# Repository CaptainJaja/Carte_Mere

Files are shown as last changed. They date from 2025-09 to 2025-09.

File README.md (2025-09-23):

# Carte mère – Coupe de France de Robotique

> Carte mère basée sur un **STM32H5** en boîtier **LQFP177**.  
> Conçue pour centraliser la communication et le pilotage des modules du robot, avec une connectique optimisée pour la robustesse et la modularité.

---

## Caractéristiques principales

- **Microcontrôleur** : STM32H5, LQFP177  
- **Interfaces série** : 12 UARTs, chacun exposé sur connecteurs **VCC – GND – TX – GND – RX** afin de permettre le torsadage avec un retour GND pour une meilleure intégrité du signal  
- **Bus I²C** : 3 bus indépendants, jusqu’à **13 connexions** possibles (chaque connecteur fournit 2 GPIOs, GND et 3V3)  
- **Convertisseurs analogiques (ADC)** : 12 entrées, rangées avec alimentation 3V3 et GND pour faciliter le câblage  
- **USB-C** : un connecteur intégré pour programmation et alimentation  
- **Timers** : 12 broches disponibles pour PWM et capture/compare  
- **GPIO** : 10 broches générales, chacune associée à GND et 3V3 pour plus de flexibilité  
- **SPI** : 4 full duplex master, avec chacun des broches power et deux gpios 

---

## Vues du PCB

### Face composants
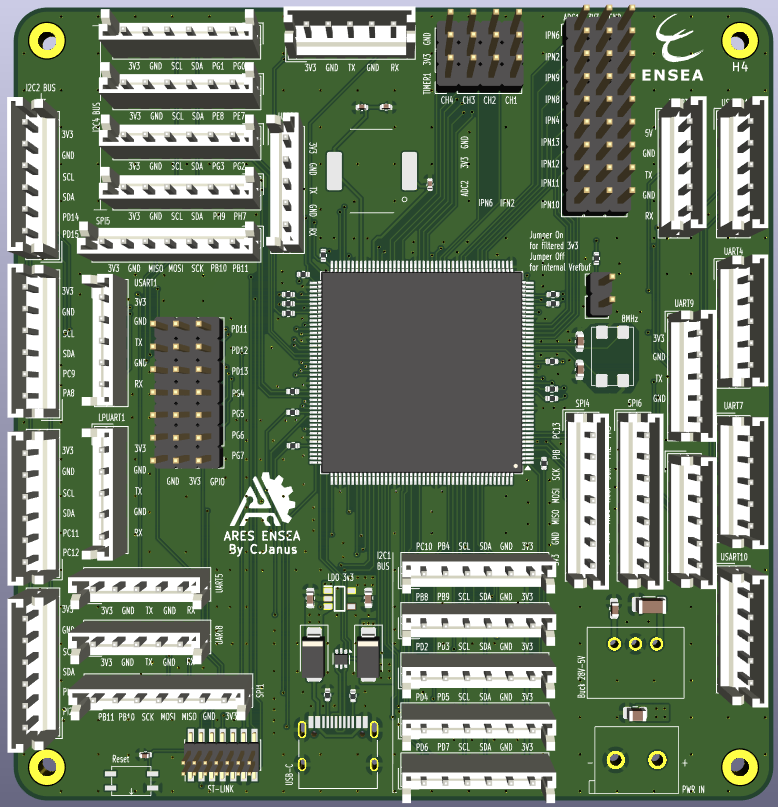
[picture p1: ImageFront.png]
PCB Face


### Face cuivre arrière
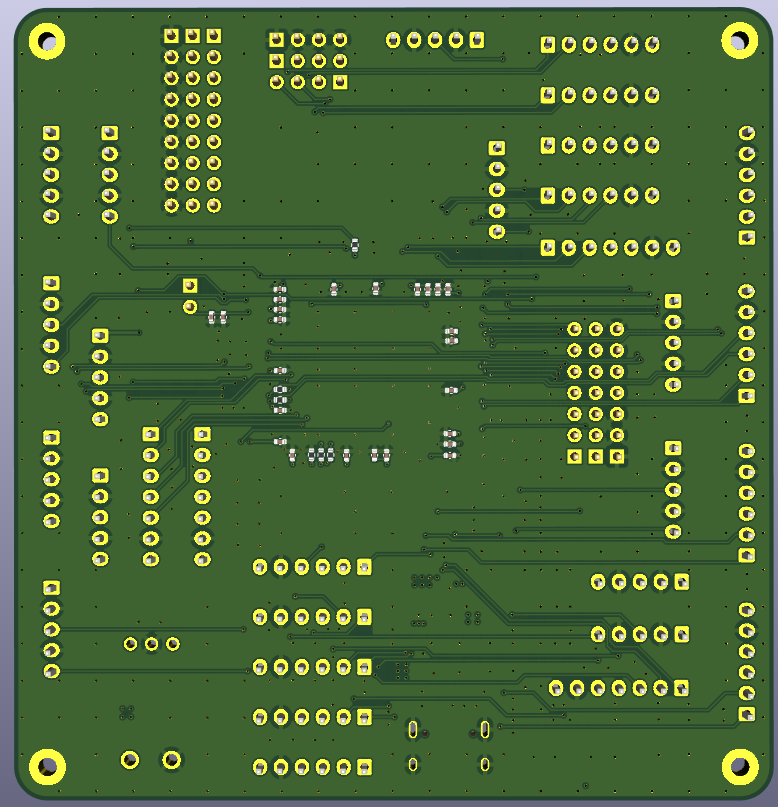
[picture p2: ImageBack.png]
PCB Dos


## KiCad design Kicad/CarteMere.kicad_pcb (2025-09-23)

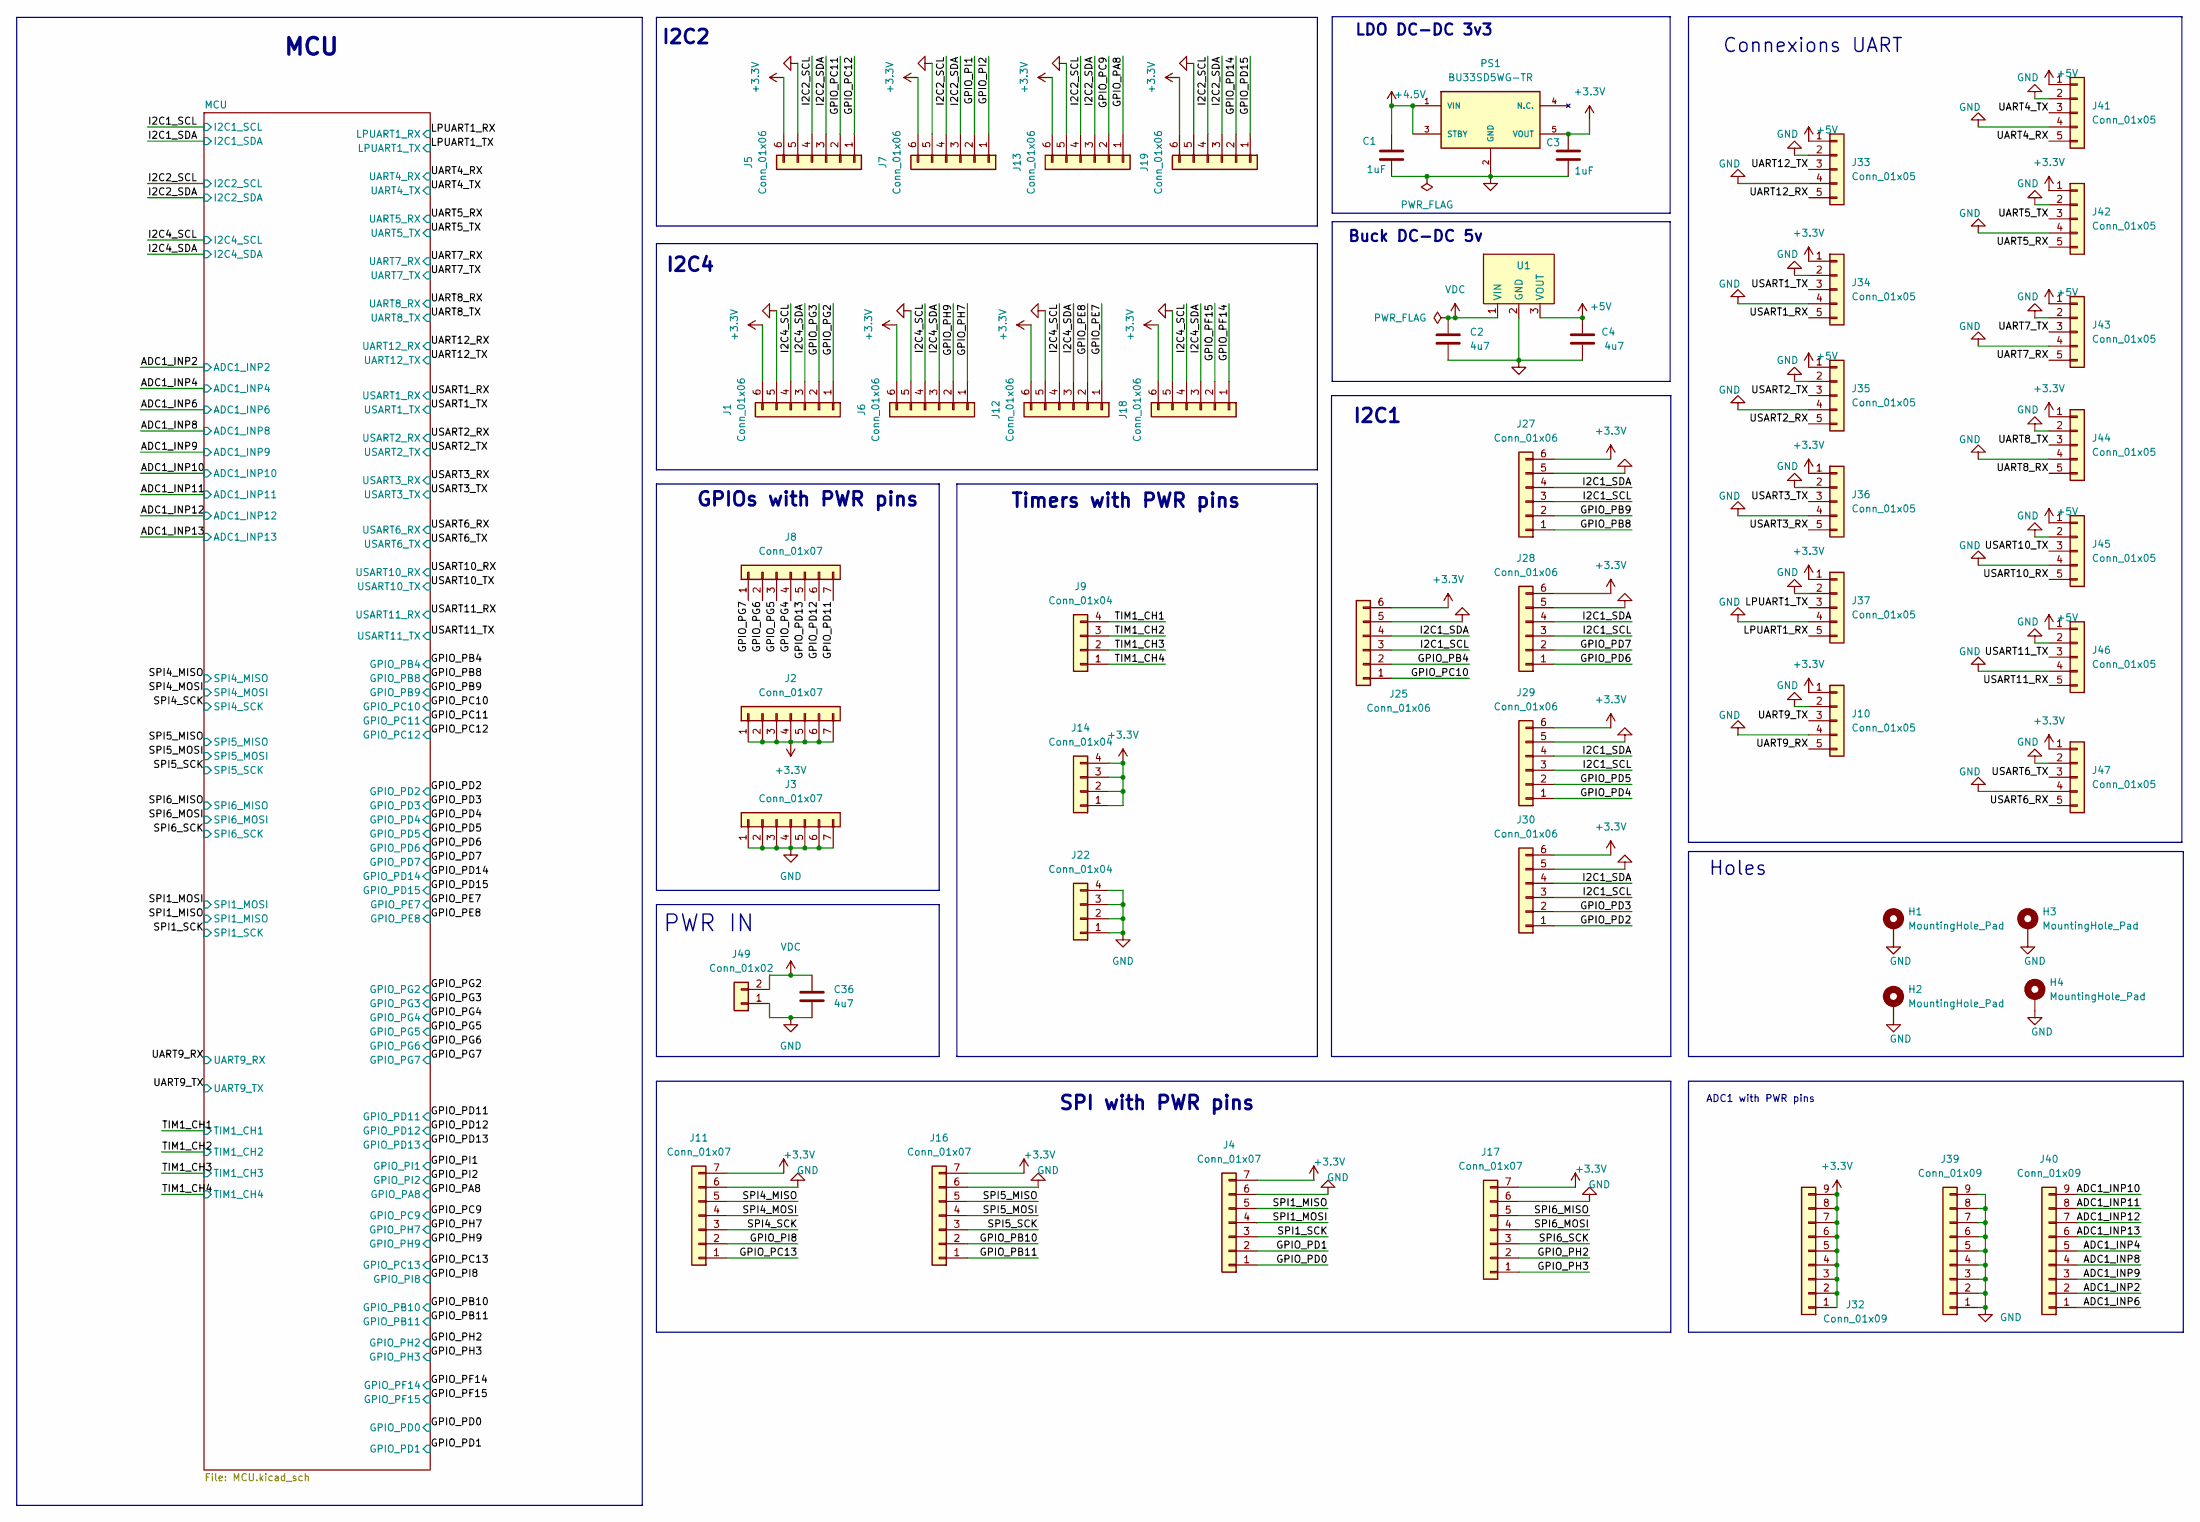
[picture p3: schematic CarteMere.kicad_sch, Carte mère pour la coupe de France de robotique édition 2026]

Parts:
C1, C3: 1uF; C_0603_1608Metric
C2: 4u7; C_1206_3216Metric
C4: 4u7; C_0603_1608Metric
C36: 4u7; C_0805_2012Metric
H1, H2, H3, H4: MountingHole_Pad; MountingHole_2.2mm_M2_Pad
J1, J5, J6, J7, J12, J13, J18, J19, J25, J27, J28, J29, J30: Conn_01x06; JST_EH_B6B-EH-A_1x06_P2.50mm_Vertical
J2, J3, J8: Conn_01x07; PinHeader_1x07_P2.54mm_Vertical
J4, J11, J16, J17: Conn_01x07; JST_EH_B7B-EH-A_1x07_P2.50mm_Vertical
J9, J14, J22: Conn_01x04; PinHeader_1x04_P2.54mm_Vertical
J10, J33, J34, J35, J36, J37, J41, J42, J43, J44, J45, J46, J47: Conn_01x05; JST_EH_B5B-EH-A_1x05_P2.50mm_Vertical
J32, J39, J40: Conn_01x09; PinHeader_1x09_P2.54mm_Vertical
J49: Conn_01x02; KF301-5.0-2P
PS1: BU33SD5WG-TR; SOT95P280X125-5N; Mouser_Part_Number 755-BU33SD5WG-TR
U1: StepDown3v3; MPN 173010x78

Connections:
+3.3V: C3.1, J1.6, J2.1, J2.2, J2.3, J2.4, J2.5, J2.6, J2.7, J4.7, J5.6, J6.6, J7.6, J10.1, J11.7, J12.6, J13.6, J14.1, J14.2, J14.3, J14.4, J16.7, J17.7, J18.6, J19.6, J25.6, J27.6, J28.6, J29.6, J30.6, J32.1, J32.2, J32.3, J32.4, J32.5, J32.6, J32.7, J32.8, J32.9, J34.1, J36.1, J37.1, J42.1, J44.1, J47.1, PS1.5 (VOUT); also elsewhere on the board
+4.5V: C1.1, PS1.1 (VIN), PS1.3 (STBY); also elsewhere on the board
+5V: C4.1, J33.1, J35.1, J41.1, J43.1, J45.1, J46.1, U1.3 (VOUT); also elsewhere on the board
/ADC1_INP2: J40.2; also elsewhere on the board
/ADC1_INP4: J40.5; also elsewhere on the board
/ADC1_INP6: J40.1; also elsewhere on the board
/ADC1_INP8: J40.4; also elsewhere on the board
/ADC1_INP9: J40.3; also elsewhere on the board
/ADC1_INP10: J40.9; also elsewhere on the board
/ADC1_INP11: J40.8; also elsewhere on the board
/ADC1_INP12: J40.7; also elsewhere on the board
/ADC1_INP13: J40.6; also elsewhere on the board
/GPIO_PA8: J13.1; also elsewhere on the board
/GPIO_PB4: J25.2; also elsewhere on the board
/GPIO_PB8: J27.1; also elsewhere on the board
/GPIO_PB9: J27.2; also elsewhere on the board
/GPIO_PB10: J16.2; also elsewhere on the board
/GPIO_PB11: J16.1; also elsewhere on the board
/GPIO_PC9: J13.2; also elsewhere on the board
/GPIO_PC10: J25.1; also elsewhere on the board
/GPIO_PC11: J5.2; also elsewhere on the board
/GPIO_PC12: J5.1; also elsewhere on the board
/GPIO_PC13: J11.1; also elsewhere on the board
/GPIO_PD0: J4.1; also elsewhere on the board
/GPIO_PD1: J4.2; also elsewhere on the board
/GPIO_PD2: J30.1; also elsewhere on the board
/GPIO_PD3: J30.2; also elsewhere on the board
/GPIO_PD4: J29.1; also elsewhere on the board
/GPIO_PD5: J29.2; also elsewhere on the board
/GPIO_PD6: J28.1; also elsewhere on the board
/GPIO_PD7: J28.2; also elsewhere on the board
/GPIO_PD11: J8.7; also elsewhere on the board
/GPIO_PD12: J8.6; also elsewhere on the board
/GPIO_PD13: J8.5; also elsewhere on the board
/GPIO_PD14: J19.2; also elsewhere on the board
/GPIO_PD15: J19.1; also elsewhere on the board
/GPIO_PE7: J12.1; also elsewhere on the board
/GPIO_PE8: J12.2; also elsewhere on the board
/GPIO_PF14: J18.1; also elsewhere on the board
/GPIO_PF15: J18.2; also elsewhere on the board
/GPIO_PG2: J1.1; also elsewhere on the board
/GPIO_PG3: J1.2; also elsewhere on the board
/GPIO_PG4: J8.4; also elsewhere on the board
/GPIO_PG5: J8.3; also elsewhere on the board
/GPIO_PG6: J8.2; also elsewhere on the board
/GPIO_PG7: J8.1; also elsewhere on the board
/GPIO_PH2: J17.2; also elsewhere on the board
/GPIO_PH3: J17.1; also elsewhere on the board
/GPIO_PH7: J6.1; also elsewhere on the board
/GPIO_PH9: J6.2; also elsewhere on the board
/GPIO_PI1: J7.2; also elsewhere on the board
/GPIO_PI2: J7.1; also elsewhere on the board
/GPIO_PI8: J11.2; also elsewhere on the board
/I2C1_SCL: J25.3, J27.3, J28.3, J29.3, J30.3; also elsewhere on the board
/I2C1_SDA: J25.4, J27.4, J28.4, J29.4, J30.4; also elsewhere on the board
/I2C2_SCL: J5.4, J7.4, J13.4, J19.4; also elsewhere on the board
/I2C2_SDA: J5.3, J7.3, J13.3, J19.3; also elsewhere on the board
/I2C4_SCL: J1.4, J6.4, J12.4, J18.4; also elsewhere on the board
/I2C4_SDA: J1.3, J6.3, J12.3, J18.3; also elsewhere on the board
/LPUART1_RX: J37.5; also elsewhere on the board
/LPUART1_TX: J37.3; also elsewhere on the board
/SPI1_MISO: J4.5; also elsewhere on the board
/SPI1_MOSI: J4.4; also elsewhere on the board
/SPI1_SCK: J4.3; also elsewhere on the board
/SPI4_MISO: J11.5; also elsewhere on the board
/SPI4_MOSI: J11.4; also elsewhere on the board
/SPI4_SCK: J11.3; also elsewhere on the board
/SPI5_MISO: J16.5; also elsewhere on the board
/SPI5_MOSI: J16.4; also elsewhere on the board
/SPI5_SCK: J16.3; also elsewhere on the board
/SPI6_MISO: J17.5; also elsewhere on the board
/SPI6_MOSI: J17.4; also elsewhere on the board
/SPI6_SCK: J17.3; also elsewhere on the board
/TIM1_CH1: J9.4; also elsewhere on the board
/TIM1_CH2: J9.3; also elsewhere on the board
/TIM1_CH3: J9.2; also elsewhere on the board
/TIM1_CH4: J9.1; also elsewhere on the board
/UART4_RX: J41.5; also elsewhere on the board
/UART4_TX: J41.3; also elsewhere on the board
/UART5_RX: J42.5; also elsewhere on the board
/UART5_TX: J42.3; also elsewhere on the board
/UART7_RX: J43.5; also elsewhere on the board
/UART7_TX: J43.3; also elsewhere on the board
/UART8_RX: J44.5; also elsewhere on the board
/UART8_TX: J44.3; also elsewhere on the board
/UART9_RX: J10.5; also elsewhere on the board
/UART9_TX: J10.3; also elsewhere on the board
/UART12_RX: J33.5; also elsewhere on the board
/UART12_TX: J33.3; also elsewhere on the board
/USART1_RX: J34.5; also elsewhere on the board
/USART1_TX: J34.3; also elsewhere on the board
/USART2_RX: J35.5; also elsewhere on the board
/USART2_TX: J35.3; also elsewhere on the board
/USART3_RX: J36.5; also elsewhere on the board
/USART3_TX: J36.3; also elsewhere on the board
/USART6_RX: J47.5; also elsewhere on the board
/USART6_TX: J47.3; also elsewhere on the board
/USART10_RX: J45.5; also elsewhere on the board
/USART10_TX: J45.3; also elsewhere on the board
/USART11_RX: J46.5; also elsewhere on the board
/USART11_TX: J46.3; also elsewhere on the board
GND: C1.2, C2.2, C3.2, C4.2, C36.2, H1.1, H2.1, H3.1, H4.1, J1.5, J3.1, J3.2, J3.3, J3.4, J3.5, J3.6, J3.7, J4.6, J5.5, J6.5, J7.5, J10.2, J10.4, J11.6, J12.5, J13.5, J16.6, J17.6, J18.5, J19.5, J22.1, J22.2, J22.3, J22.4, J25.5, J27.5, J28.5, J29.5, J30.5, J33.2, J33.4, J34.2, J34.4, J35.2, J35.4, J36.2, J36.4, J37.2, J37.4, J39.1, J39.2, J39.3, J39.4, J39.5, J39.6, J39.7, J39.8, J39.9, J41.2, J41.4, J42.2, J42.4, J43.2, J43.4, J44.2, J44.4, J45.2, J45.4, J46.2, J46.4, J47.2, J47.4, J49.1, PS1.2 (GND), U1.2 (GND); also elsewhere on the board
VDC: C2.1, C36.1, J49.2, U1.1 (VIN)

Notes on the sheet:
SPI with PWR pins
I2C2
MCU
PWR IN
I2C4
Connexions UART
Buck DC-DC 5v
LDO DC-DC 3v3
GPIOs with PWR pins
Timers with PWR pins
I2C1
ADC1 with PWR pins
Holes

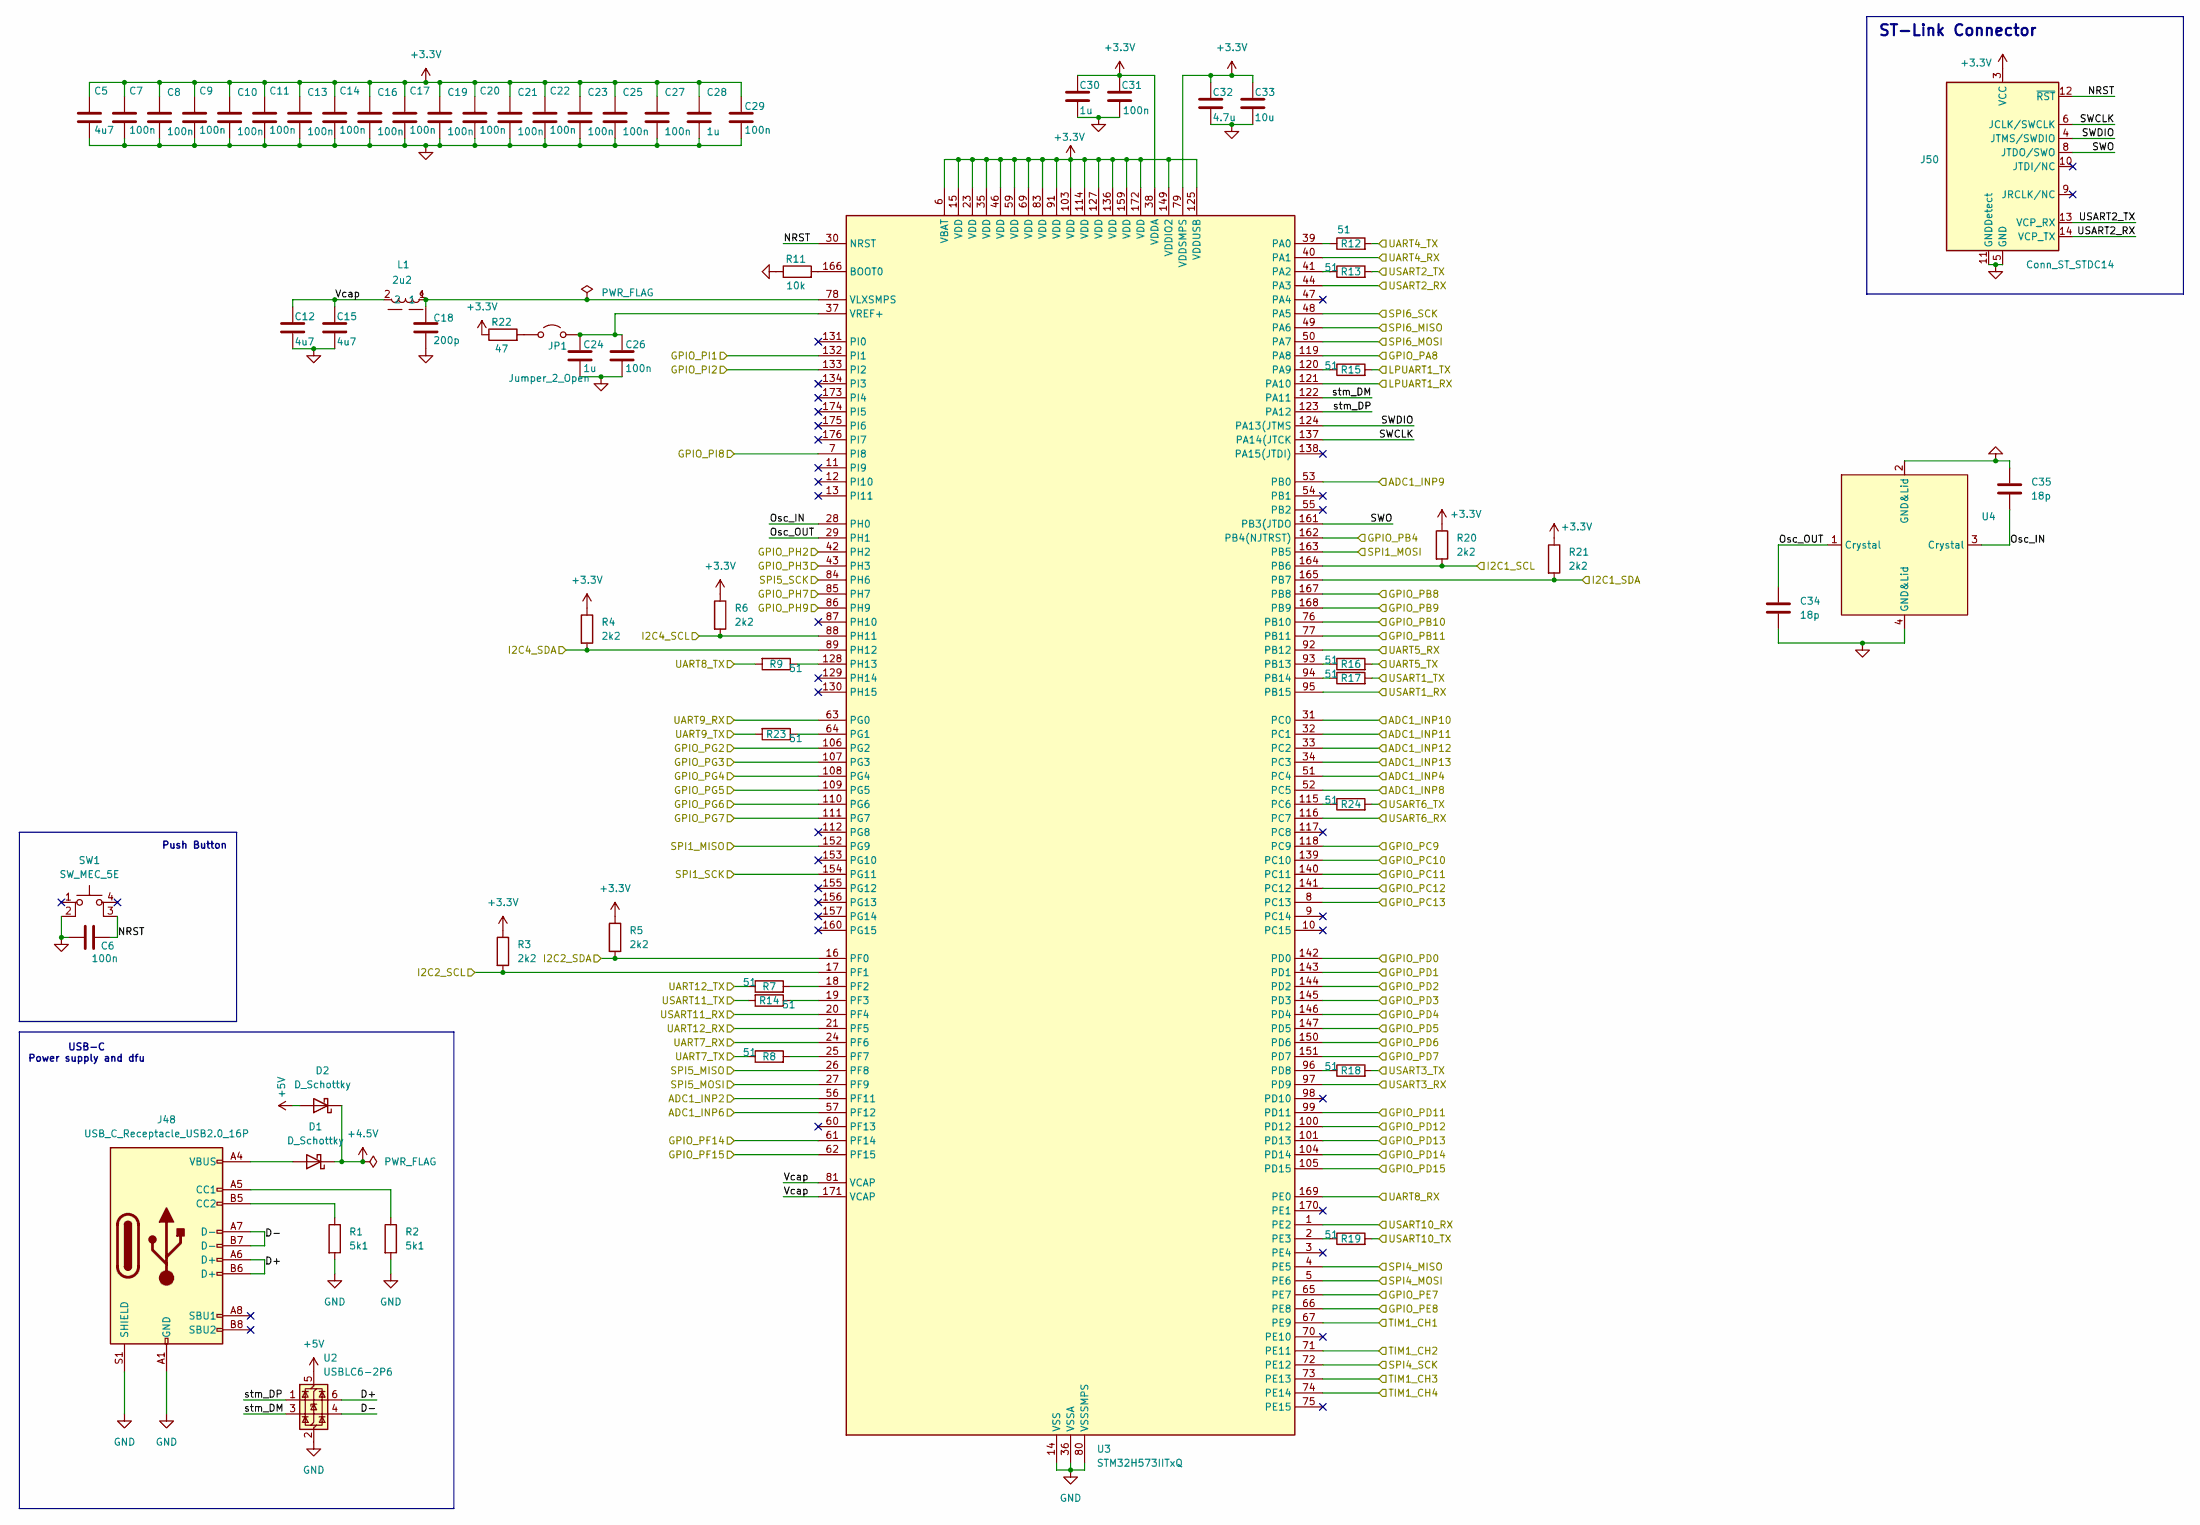
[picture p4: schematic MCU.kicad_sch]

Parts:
C5, C12, C15: 4u7; C_0402_1005Metric
C6, C7, C8, C9, C10, C11, C13, C14, C16, C17, C19, C20, C21, C22, C23, C25, C26, C27, C29, C31: 100n; C_0402_1005Metric
C18: 200p; C_0402_1005Metric
C24, C28, C30: 1u; C_0402_1005Metric
C32: 4.7u; C_0402_1005Metric
C33: 10u; C_0402_1005Metric
C34, C35: 18p; C_0603_1608Metric
D1, D2: D_Schottky; D_SMA
J48: USB_C_Receptacle_USB2.0_16P; USB_C_Receptacle_HRO_TYPE-C-31-M-12
J50: Conn_ST_STDC14; PinHeader_2x07_P1.27mm_Vertical_SMD
JP1: Jumper_2_Open; PinHeader_1x02_P2.54mm_Vertical
L1: 2u2; 7440660022
R1, R2: 5k1; R_0402_1005Metric
R3, R4, R5, R6, R20, R21: 2k2; R_0402_1005Metric
R7, R8, R9, R12, R13, R14, R15, R16, R17, R18, R19, R23, R24: 51; R_0402_1005Metric
R11: 10k; R_0402_1005Metric
R22: 47; R_0402_1005Metric
SW1: SW_MEC_5E; WS-TASU SMT Tact Switch 4.7x3.5 mm side push
U2: USBLC6-2P6; SOT-666
U3: STM32H573IITxQ; LQFP-176_24x24mm_P0.5mm
U4: WE-XTAL Quartz Crystal 8MHz

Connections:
+3.3V: C5.1, C7.1, C8.1, C9.1, C10.1, C11.1, C13.1, C14.1, C16.1, C17.1, C19.1, C20.1, C21.1, C22.1, C23.1, C25.1, C27.1, C28.1, C29.1, C30.1, C31.1, C32.1, C33.1, J50.3 (VCC), R3.1, R4.1, R5.1, R6.1, R20.1, R21.1, R22.1, U3.6 (VBAT), U3.15 (VDD), U3.23 (VDD), U3.35 (VDD), U3.38 (VDDA), U3.46 (VDD), U3.59 (VDD), U3.69 (VDD), U3.79 (VDDSMPS), U3.83 (VDD), U3.91 (VDD), U3.103 (VDD), U3.114 (VDD), U3.125 (VDDUSB), U3.127 (VDD), U3.136 (VDD), U3.149 (VDDIO2), U3.159 (VDD), U3.172 (VDD); also elsewhere on the board
+4.5V: D1.1 (K), D2.1 (K); also elsewhere on the board
+5V: D2.2 (A), U2.5 (VBUS); also elsewhere on the board
/ADC1_INP2: U3.56 (PF11); also elsewhere on the board
/ADC1_INP4: U3.51 (PC4); also elsewhere on the board
/ADC1_INP6: U3.57 (PF12); also elsewhere on the board
/ADC1_INP8: U3.52 (PC5); also elsewhere on the board
/ADC1_INP9: U3.53 (PB0); also elsewhere on the board
/ADC1_INP10: U3.31 (PC0); also elsewhere on the board
/ADC1_INP11: U3.32 (PC1); also elsewhere on the board
/ADC1_INP12: U3.33 (PC2); also elsewhere on the board
/ADC1_INP13: U3.34 (PC3); also elsewhere on the board
/GPIO_PA8: U3.119 (PA8); also elsewhere on the board
/GPIO_PB4: U3.162 (PB4(NJTRST)); also elsewhere on the board
/GPIO_PB8: U3.167 (PB8); also elsewhere on the board
/GPIO_PB9: U3.168 (PB9); also elsewhere on the board
/GPIO_PB10: U3.76 (PB10); also elsewhere on the board
/GPIO_PB11: U3.77 (PB11); also elsewhere on the board
/GPIO_PC9: U3.118 (PC9); also elsewhere on the board
/GPIO_PC10: U3.139 (PC10); also elsewhere on the board
/GPIO_PC11: U3.140 (PC11); also elsewhere on the board
/GPIO_PC12: U3.141 (PC12); also elsewhere on the board
/GPIO_PC13: U3.8 (PC13); also elsewhere on the board
/GPIO_PD0: U3.142 (PD0); also elsewhere on the board
/GPIO_PD1: U3.143 (PD1); also elsewhere on the board
/GPIO_PD2: U3.144 (PD2); also elsewhere on the board
/GPIO_PD3: U3.145 (PD3); also elsewhere on the board
/GPIO_PD4: U3.146 (PD4); also elsewhere on the board
/GPIO_PD5: U3.147 (PD5); also elsewhere on the board
/GPIO_PD6: U3.150 (PD6); also elsewhere on the board
/GPIO_PD7: U3.151 (PD7); also elsewhere on the board
/GPIO_PD11: U3.99 (PD11); also elsewhere on the board
/GPIO_PD12: U3.100 (PD12); also elsewhere on the board
/GPIO_PD13: U3.101 (PD13); also elsewhere on the board
/GPIO_PD14: U3.104 (PD14); also elsewhere on the board
/GPIO_PD15: U3.105 (PD15); also elsewhere on the board
/GPIO_PE7: U3.65 (PE7); also elsewhere on the board
/GPIO_PE8: U3.66 (PE8); also elsewhere on the board
/GPIO_PF14: U3.61 (PF14); also elsewhere on the board
/GPIO_PF15: U3.62 (PF15); also elsewhere on the board
/GPIO_PG2: U3.106 (PG2); also elsewhere on the board
/GPIO_PG3: U3.107 (PG3); also elsewhere on the board
/GPIO_PG4: U3.108 (PG4); also elsewhere on the board
/GPIO_PG5: U3.109 (PG5); also elsewhere on the board
/GPIO_PG6: U3.110 (PG6); also elsewhere on the board
/GPIO_PG7: U3.111 (PG7); also elsewhere on the board
/GPIO_PH2: U3.42 (PH2); also elsewhere on the board
/GPIO_PH3: U3.43 (PH3); also elsewhere on the board
/GPIO_PH7: U3.85 (PH7); also elsewhere on the board
/GPIO_PH9: U3.86 (PH9); also elsewhere on the board
/GPIO_PI1: U3.132 (PI1); also elsewhere on the board
/GPIO_PI2: U3.133 (PI2); also elsewhere on the board
/GPIO_PI8: U3.7 (PI8); also elsewhere on the board
/I2C1_SCL: R20.2, U3.164 (PB6); also elsewhere on the board
/I2C1_SDA: R21.2, U3.165 (PB7); also elsewhere on the board
/I2C2_SCL: R3.2, U3.17 (PF1); also elsewhere on the board
/I2C2_SDA: R5.2, U3.16 (PF0); also elsewhere on the board
/I2C4_SCL: R6.2, U3.88 (PH11); also elsewhere on the board
/I2C4_SDA: R4.2, U3.89 (PH12); also elsewhere on the board
/LPUART1_RX: U3.121 (PA10); also elsewhere on the board
/LPUART1_TX: R15.2; also elsewhere on the board
/MCU/D+: J48.A6 (D+), J48.B6 (D+), U2.6 (I/O1)
/MCU/D-: J48.A7 (D-), J48.B7 (D-), U2.4 (I/O2)
/MCU/NRST: C6.2, J50.12 (~RST), SW1.3 (K), U3.30 (NRST)
/MCU/Osc_IN: C35.2, U3.28 (PH0), U4.3 (Crystal)
/MCU/Osc_OUT: C34.1, U3.29 (PH1), U4.1 (Crystal)
/MCU/SWCLK: J50.6 (JCLK/SWCLK), U3.137 (PA14(JTCK)
/MCU/SWDIO: J50.4 (JTMS/SWDIO), U3.124 (PA13(JTMS)
/MCU/SWO: J50.8 (JTDO/SWO), U3.161 (PB3(JTDO)
/MCU/Vcap: C12.1, C15.1, L1.2, U3.81 (VCAP), U3.171 (VCAP)
/MCU/stm_DM: U2.3 (I/O2), U3.122 (PA11)
/MCU/stm_DP: U2.1 (I/O1), U3.123 (PA12)
/SPI1_MISO: U3.152 (PG9); also elsewhere on the board
/SPI1_MOSI: U3.163 (PB5); also elsewhere on the board
/SPI1_SCK: U3.154 (PG11); also elsewhere on the board
/SPI4_MISO: U3.4 (PE5); also elsewhere on the board
/SPI4_MOSI: U3.5 (PE6); also elsewhere on the board
/SPI4_SCK: U3.72 (PE12); also elsewhere on the board
/SPI5_MISO: U3.26 (PF8); also elsewhere on the board
/SPI5_MOSI: U3.27 (PF9); also elsewhere on the board
/SPI5_SCK: U3.84 (PH6); also elsewhere on the board
/SPI6_MISO: U3.49 (PA6); also elsewhere on the board
/SPI6_MOSI: U3.50 (PA7); also elsewhere on the board
/SPI6_SCK: U3.48 (PA5); also elsewhere on the board
/TIM1_CH1: U3.67 (PE9); also elsewhere on the board
/TIM1_CH2: U3.71 (PE11); also elsewhere on the board
/TIM1_CH3: U3.73 (PE13); also elsewhere on the board
/TIM1_CH4: U3.74 (PE14); also elsewhere on the board
/UART4_RX: U3.40 (PA1); also elsewhere on the board
/UART4_TX: R12.2; also elsewhere on the board
/UART5_RX: U3.92 (PB12); also elsewhere on the board
/UART5_TX: R16.2; also elsewhere on the board
/UART7_RX: U3.24 (PF6); also elsewhere on the board
/UART7_TX: R8.1; also elsewhere on the board
/UART8_RX: U3.169 (PE0); also elsewhere on the board
/UART8_TX: R9.2; also elsewhere on the board
/UART9_RX: U3.63 (PG0); also elsewhere on the board
/UART9_TX: R23.2; also elsewhere on the board
/UART12_RX: U3.21 (PF5); also elsewhere on the board
/UART12_TX: R7.1; also elsewhere on the board
/USART1_RX: U3.95 (PB15); also elsewhere on the board
/USART1_TX: R17.2; also elsewhere on the board
/USART2_RX: J50.14 (VCP_TX), U3.44 (PA3); also elsewhere on the board
/USART2_TX: J50.13 (VCP_RX), R13.2; also elsewhere on the board
/USART3_RX: U3.97 (PD9); also elsewhere on the board
/USART3_TX: R18.2; also elsewhere on the board
/USART6_RX: U3.116 (PC7); also elsewhere on the board
/USART6_TX: R24.2; also elsewhere on the board
/USART10_RX: U3.1 (PE2); also elsewhere on the board
/USART10_TX: R19.2; also elsewhere on the board
/USART11_RX: U3.20 (PF4); also elsewhere on the board
/USART11_TX: R14.2; also elsewhere on the board
GND: C5.2, C6.1, C7.2, C8.2, C9.2, C10.2, C11.2, C12.2, C13.2, C14.2, C15.2, C16.2, C17.2, C18.2, C19.2, C20.2, C21.2, C22.2, C23.2, C24.2, C25.2, C26.2, C27.2, C28.2, C29.2, C30.2, C31.2, C32.2, C33.2, C34.2, C35.1, J48.A1 (GND), J48.A12 (GND), J48.B1 (GND), J48.B12 (GND), J48.S1 (SHIELD), J50.5 (GND), J50.7 (GND), J50.11 (GNDDetect), R1.2, R2.2, R11.1, SW1.2, U2.2 (GND), U3.14 (VSS), U3.22 (VSS), U3.36 (VSSA), U3.45 (VSS), U3.58 (VSS), U3.68 (VSS), U3.80 (VSSSMPS), U3.82 (VSS), U3.90 (VSS), U3.102 (VSS), U3.113 (VSS), U3.126 (VSS), U3.135 (VSS), U3.148 (VSS), U3.158 (VSS), U4.2 (GND&Lid), U4.4 (GND&Lid); also elsewhere on the board
unnamed: D1.2 (A), J48.A4 (VBUS), J48.A9 (VBUS), J48.B4 (VBUS), J48.B9 (VBUS)
unnamed: J48.A5 (CC1), R2.1
unnamed: J48.B5 (CC2), R1.1
unnamed: JP1.1 (A), R22.2
unnamed: C24.1, C26.1, JP1.2 (B), U3.37 (VREF+)
unnamed: R11.2, U3.166 (BOOT0)
unnamed: R12.1, U3.39 (PA0)
unnamed: R13.1, U3.41 (PA2)
unnamed: R15.1, U3.120 (PA9)
unnamed: R16.1, U3.93 (PB13)
unnamed: R17.1, U3.94 (PB14)
unnamed: R24.1, U3.115 (PC6)
unnamed: R18.1, U3.96 (PD8)
unnamed: R19.1, U3.2 (PE3)
unnamed: R7.2, U3.18 (PF2)
unnamed: R14.1, U3.19 (PF3)
unnamed: R8.2, U3.25 (PF7)
unnamed: R23.1, U3.64 (PG1)
unnamed: R9.1, U3.128 (PH13)
unnamed: C18.1, L1.1, U3.78 (VLXSMPS)

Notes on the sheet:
USB-C Power supply and dfu
Push Button
ST-Link Connector

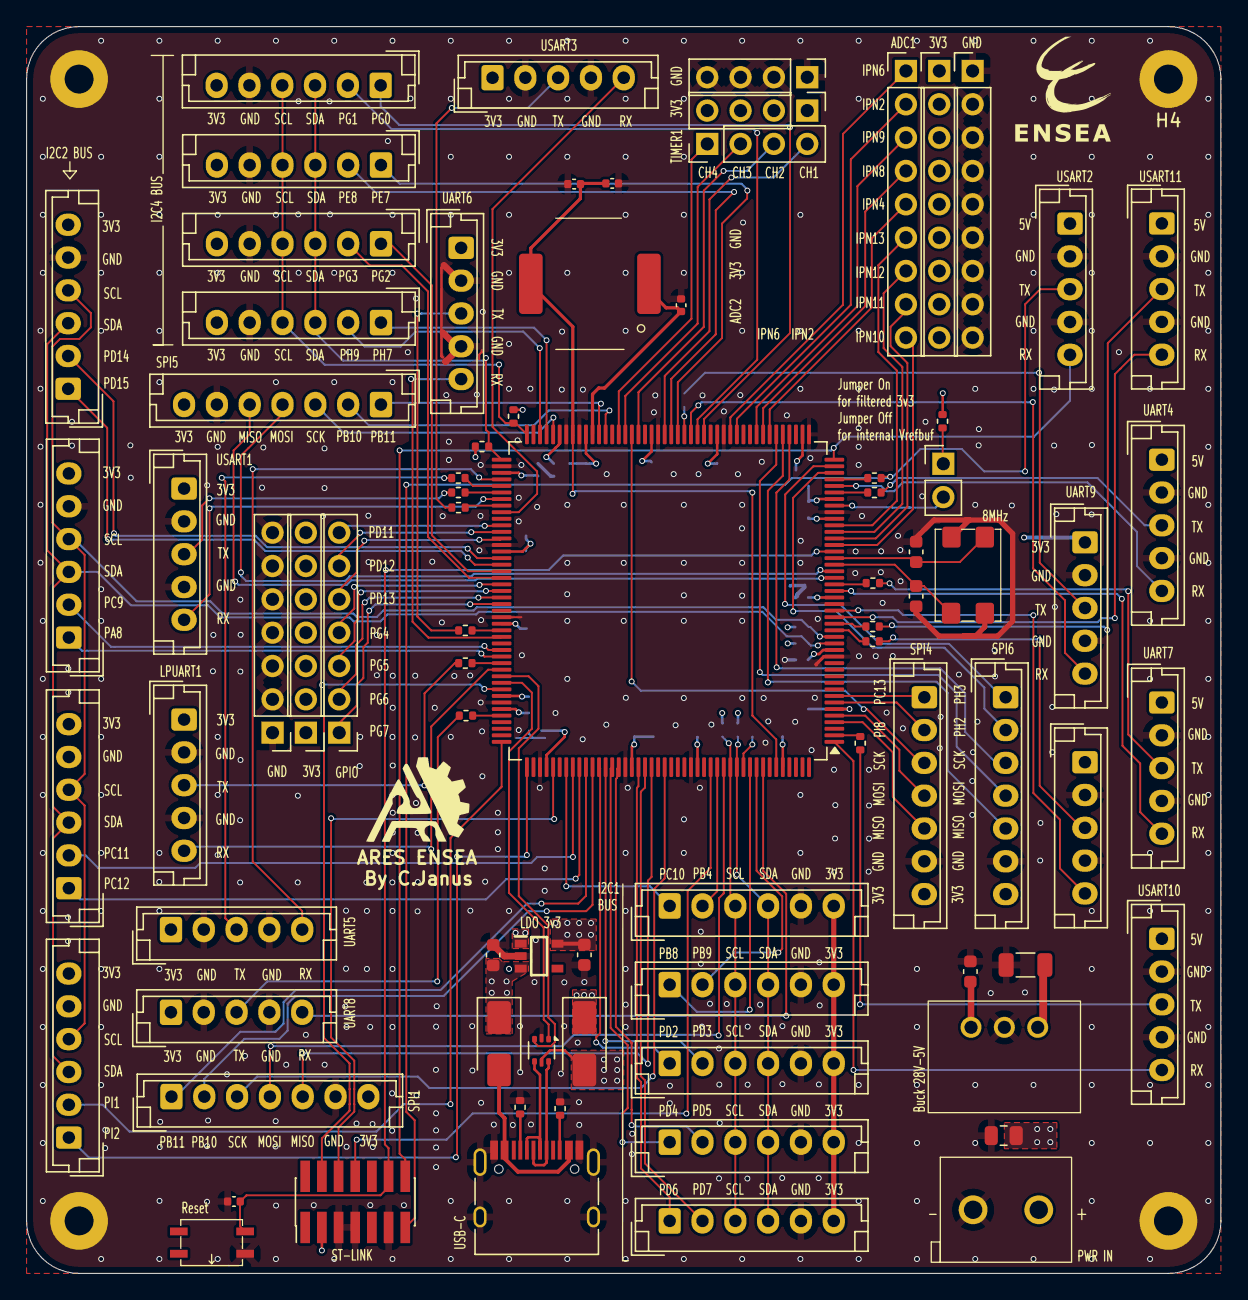
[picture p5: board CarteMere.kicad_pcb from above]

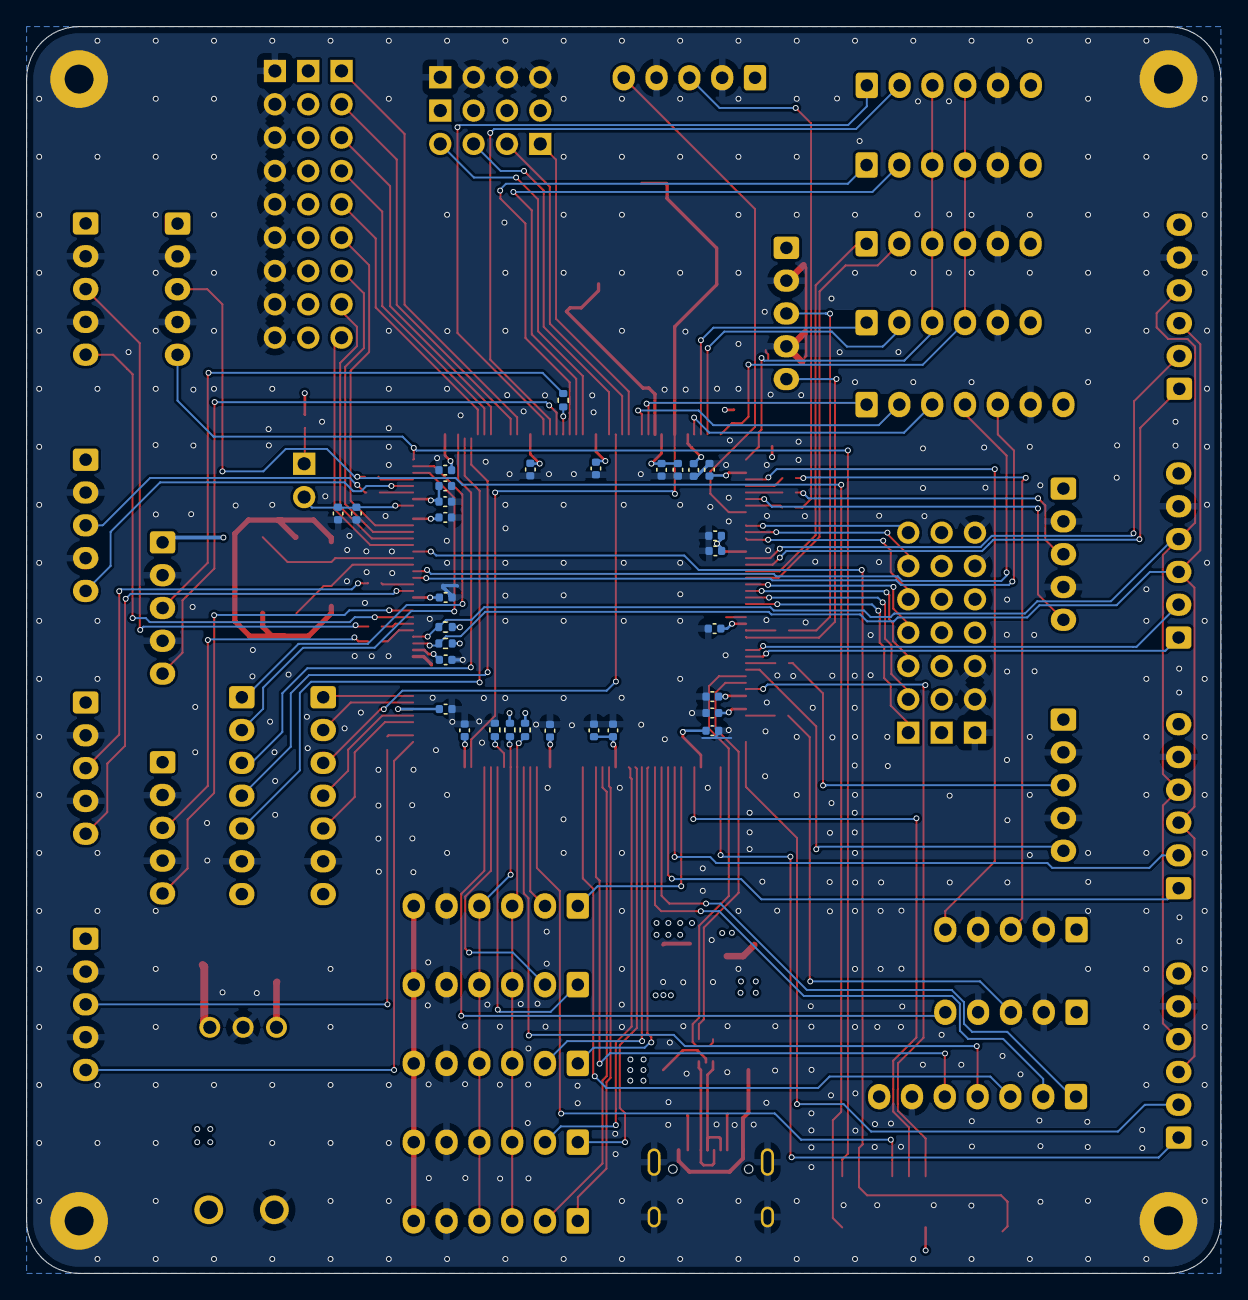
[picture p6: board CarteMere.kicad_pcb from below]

Board: 4 copper layers, 91.0 x 95.0 mm, 115 parts (31 on the bottom side), 134 nets.

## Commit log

2025-09-16 ajout du projet kicad carte mere
    [CarteMere.kicad_pcb, CarteMere.kicad_sch, MCU.kicad_sch]
2025-09-16 ajout images du projet kicad carte mere
2025-09-21 ajout spi et maj readme
    [CarteMere.kicad_pcb, CarteMere.kicad_sch, MCU.kicad_sch]
2025-09-21 final push--ajout des vias
    [CarteMere-B_Cu.gbr, CarteMere-B_Mask.gbr, CarteMere-B_Paste.gbr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]
2025-09-23 ajout d'un connecteur SPI
    [CarteMere-B_Cu.gbr, CarteMere-B_Mask.gbr, CarteMere-B_Paste.gbr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]
